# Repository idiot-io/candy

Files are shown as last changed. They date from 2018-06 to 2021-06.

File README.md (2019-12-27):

more at [idiot.io](idiot.io)

# candy
Electrodible lolliPCBpops

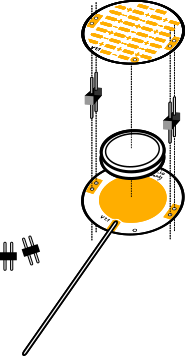
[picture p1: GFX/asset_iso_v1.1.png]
iso look
 

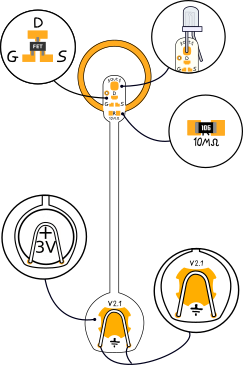
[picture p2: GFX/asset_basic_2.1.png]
basic look
 

34c3 [video](https://www.youtube.com/watch?v=yhNaNCrcmBk) cooking show and talk  

## tools
using [inkscape](https://inkscape.org) with [svg2shenzen](https://github.com/badgeek/svg2shenzhen) extension - a wrapper/fork to [Kicad's](https://kicad.github.io) own bitmap2component plugin.  
basicly - design a board in SVG vector format and export it as gerber files, ready for fabrication.  

included in the repo is a script to automate the gerber file generation.  
so after you run `extensins>svg2shenzhen>export`  
run  
```python2 ../kicad_gerber_gen.py IRiotCandy-svg2shnzn.kicad_pcb```

[gerbv](http://gerbv.geda-project.org) was then used to preview the gerber output and move the silkscreen to its right position. if you have it in your path, the previous python script should auto open the generate dgerber files fo you.

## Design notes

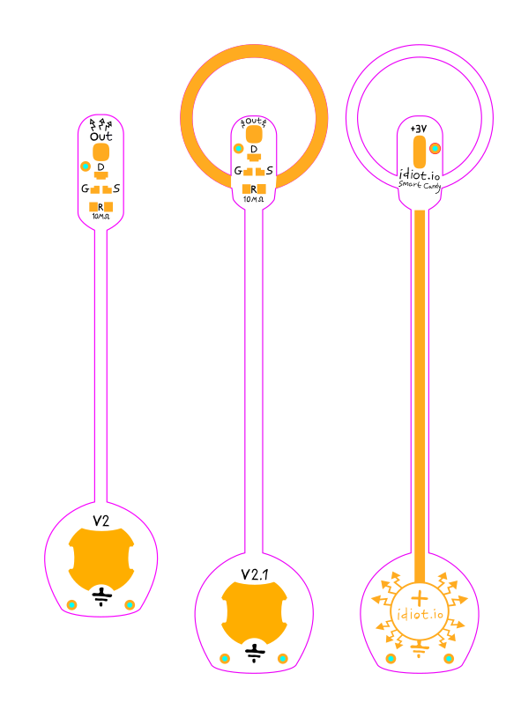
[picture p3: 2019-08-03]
hardware/BasicCandyV2.1.png

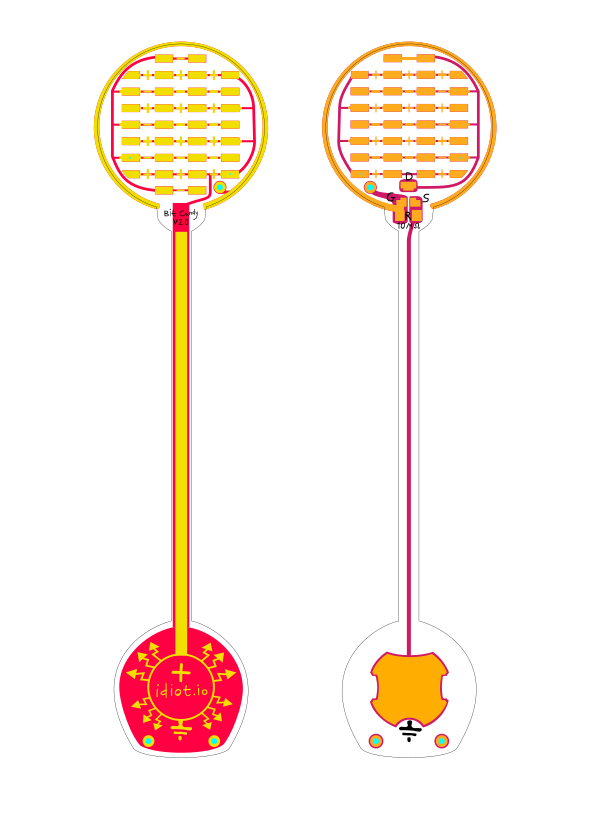
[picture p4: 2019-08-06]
hardware/BitCandyV2.0.png

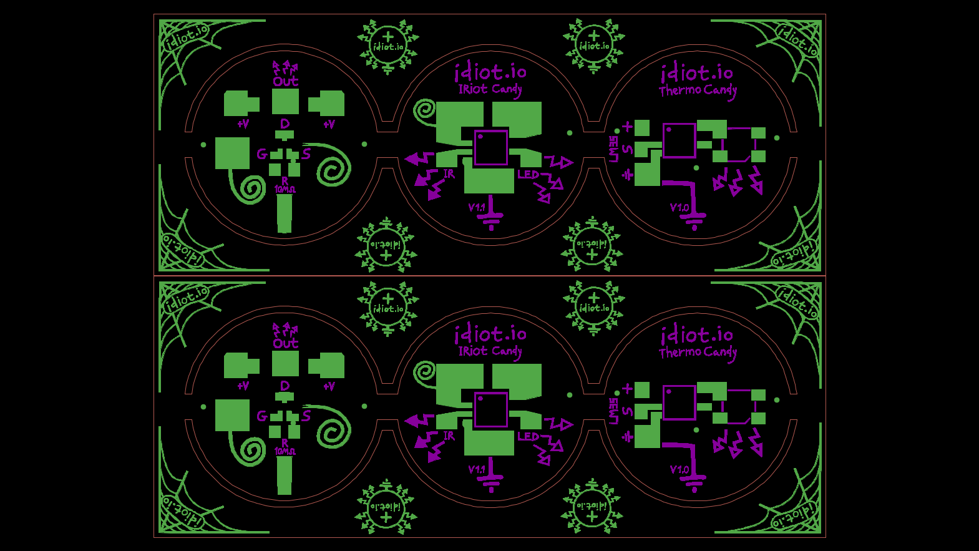
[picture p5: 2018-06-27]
hardware/releases/gerber-panelInkscape-double.png

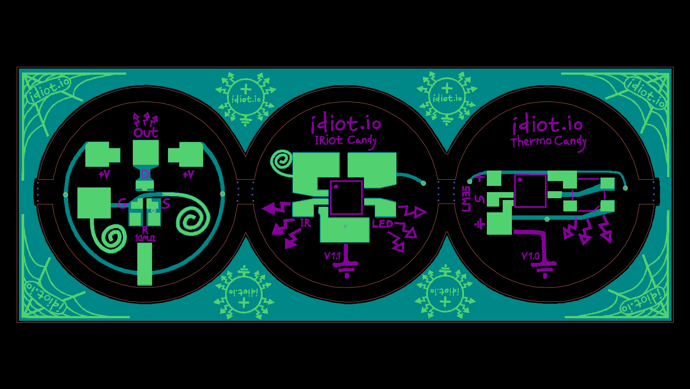
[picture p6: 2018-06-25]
hardware/releases/gerber-panelInkscape.png

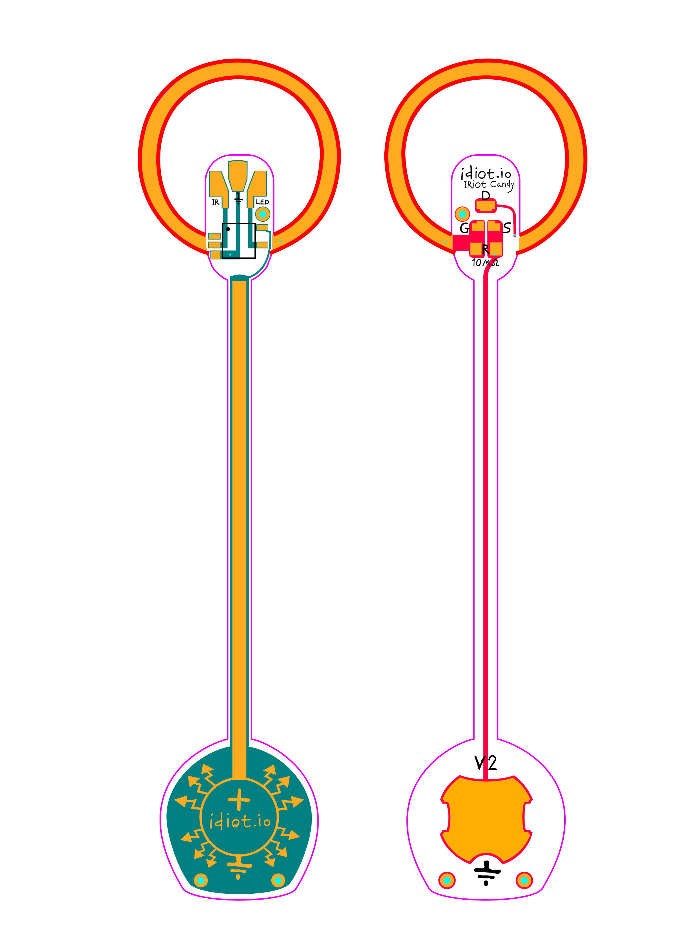
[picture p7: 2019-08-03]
hardware/IRiotCandyV2.0.png

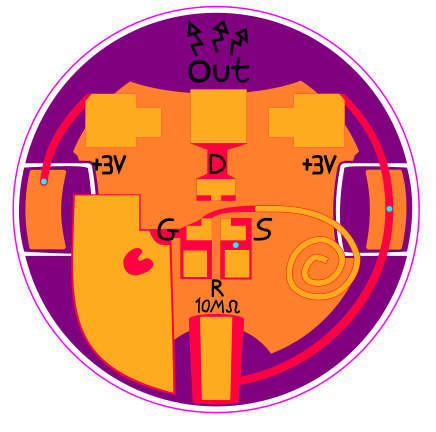
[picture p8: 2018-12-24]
hardware/releases/basicCandy-single-24122018.png

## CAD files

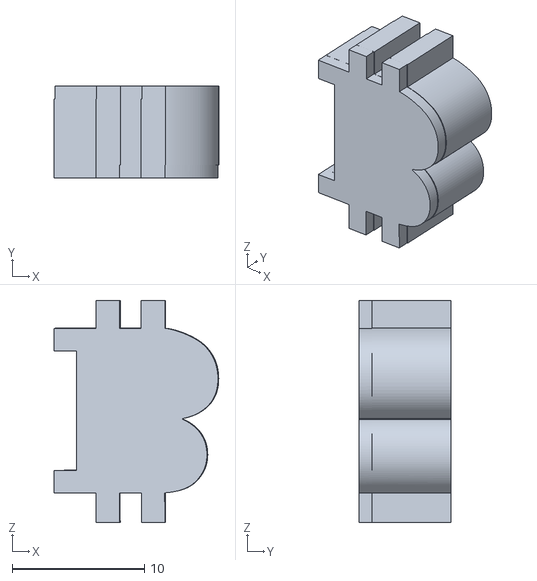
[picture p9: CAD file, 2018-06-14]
GFX/stl-models/candycoin.stl
12.5 x 7.00 x 16.8

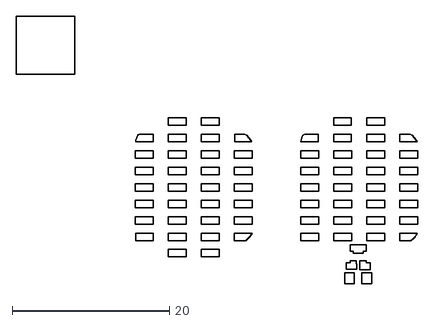
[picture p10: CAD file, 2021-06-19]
hardware/BitCandyStencil/BitCandyStencil.dxf
51.1 x 34.1

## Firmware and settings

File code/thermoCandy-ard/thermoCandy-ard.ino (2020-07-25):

/*
  ThermoCandy
   for kids only

   words http://idiot.io
   code https://github.com/shenkarSElab/IRiot/thermoCandy

   pin out attiny85
   NC      -1+----+8- VCC
   NC      -2|*   |7- NC
   Thermo  -3|    |6- Pixel
   GND     -4+----+5- Serial (debug)
   http://drazzy.com/e/img/PinoutT85a.jpg
*/

///////////////////////////////////////////////
///https://forum.arduino.cc/index.php?topic=112013.msg841582#msg841582
#include "SendOnlySoftwareSerial.h"
SendOnlySoftwareSerial mySerial (0);  // Tx pin , PB0, pin5

////////////////////////////////////////////////
//https://github.com/adafruit/Adafruit_NeoPixel
#include <Adafruit_NeoPixel.h>
#ifdef __AVR__
#include <avr/power.h>
#endif
#define pixelPin 1 //PB1, pin6
Adafruit_NeoPixel pixels = Adafruit_NeoPixel(1, pixelPin, NEO_GRB + NEO_KHZ800);

///////////////////////////////
// https://github.com/MajenkoLibraries/Average
#include "Average.h"
Average<float> ave(30);
int sensorPin = A2; //pin 3


//pixels
byte red, green, blue;

//#define range 0 //RAINBOWS
#define range 1 //test heat
//#define range 2   //fancy

int ledState, getout, blinkRate;
unsigned long prevMillis1, prevMillis2  = 0;

void setup() {
  mySerial.begin(9600);

  pixels.begin();
}

void loop() {
  unsigned long currentMillis = millis();

  int analogValue = analogRead(sensorPin);
  long temperature = (readVcc() / 1000.0) * analogValue * 100.0 / 1024;

  ave.push(temperature);
  float average = ave.mean();


  switch (range) {
    case 0:
      //rainbows pixel test
      for (int i = 0; i < 255; i++) {
        green = i;
        red = i - 255;
        blue = 0;
      }
      break;
    case 1:
      getout = 0;
      if (average > 20  && average < 35) {
        red = 0;
        green = 255;
        blue = 0;
      } else if (average >= 36.5 && average < 120) {
        red = 200;
        green = 0;
        blue = 0;
      } else if (average >= 120) {

        getout = 1;

        blinkRate = map( constrain(average, 146, 120) , 146, 120, 500, 50);
        red = ledState * 255;
        green = 0;
        blue = 0;
      }


      break;
    case 2:
      //fancy
      byte red, green, blue;
      if (average > 20  && average < 35) {
        green = mapfloat(average, 20, 37, 0, 255);
        blue = 255 - red;
        red = 0;
      } else if (average >= 35  && average < 36.5) {
        red = mapfloat(average, 24, 37, 0, 255);
        green = 255 - red;
        blue = 0;
      } else if (average >= 36.5 && average < 100) {
        red = mapfloat(average, 36.5, 37, 0, 255);
        green = 0;
        blue = 0;
      } else if (average >= 100) {
        red = ledState;
        green = 0;
        blue = 0;
      }

      break;
  }


  pixels.setPixelColor(0, pixels.Color(red, green, blue));
  pixels.show();

  if (currentMillis - prevMillis1 >= 50) {

    // And show some interesting results.
    mySerial.print(average);
    mySerial.print(" ");
    mySerial.print(temperature);

    mySerial.print(" ");
    mySerial.print(blinkRate);
    mySerial.print(" ");
    mySerial.print(ledState);

    /*
        mySerial.print(" ");
        mySerial.print(red);
        mySerial.print(" ");
        mySerial.print(green);
        mySerial.print(" ");
        mySerial.print(blue);
    */
    mySerial.println();
  }

  //700=interval
  if (currentMillis - prevMillis2 >= blinkRate) {
    prevMillis2 = currentMillis;
    if (ledState) {
      ledState = false;
    } else {
      ledState = true;
    }
  }


}
// This code snippet is made by Tinkerit. Open Source license. Slightly modified by DavidJWatts
long readVcc() {
  // Read 1.1V reference against AVcc
  long result;
  // set the reference to Vcc and the measurement to the internal 1.1V reference
  ADMUX = _BV(MUX3) | _BV(MUX2);

  delay(2); // Wait for Vref to settle
  ADCSRA |= _BV(ADSC); // Convert
  while (bit_is_set(ADCSRA, ADSC));
  result = ADCL;
  result |= ADCH << 8;
  result = 1126400L / result; // Back-calculate AVcc in mV
  return result;
}

float mapfloat(long x, long in_min, long in_max, long out_min, long out_max)
{
  return (float)(x - in_min) * (out_max - out_min) / (float)(in_max - in_min) + out_min;
}

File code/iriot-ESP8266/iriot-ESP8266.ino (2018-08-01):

/*
    test on your server with
    $ mosquitto_sub -h 127.0.0.1 -i testSub -t outLicks
  =ESP8266 board=
  //  to install ESP8266 in arduino IDE
  https://github.com/esp8266/Arduino#installing-with-boards-manager

  =libraries to install=
    adafruit gfx library
    adafruit SSD1306
    IRremoteWSP8266
    PubSubClient
    WifiManager

  =nodeMCU pinout =
    ==IR CHQ1838==
    // package facing you
    // from left to right
    D5/14
    GND
    3V3

    ==OLED SD1306==
    GND
    3V3
    D1/SCL
    D2/SDA
*/

/////////////////////////////////////////////////////////////////////////////
//wifi manager     https://github.com/tzapu/WiFiManager
#include <ESP8266WiFi.h>          //https://github.com/esp8266/Arduino
#include <DNSServer.h>
#include <ESP8266WebServer.h>
#include <WiFiManager.h>

/////////////////////////////////////////////////////////////////////////////
//irRemote code https://github.com/markszabo/IRremoteESP8266/wiki#ir-receiving
#include <IRremoteESP8266.h>
#include <IRrecv.h>
#include <IRutils.h>
uint16_t RECV_PIN = 14; // An IR detector/demodulator is connected to GPIO pin 14(D5 on a NodeMCU).
IRrecv irrecv(RECV_PIN);
decode_results results;

/////////////////////////////////////////////////////////////////////////////
//mqtt broker https://github.com/knolleary/pubsubclient - http://pubsubclient.knolleary.net/
#include <PubSubClient.h>
WiFiClient espClient;
PubSubClient client(espClient);
const char* mqtt_server = "idiot.io";

/////////////////////////////////////////////////
//// OLED aliexpress ssd1306
// see setup https://www.youtube.com/watch?v=RpK7-Ljnpho
#include <Adafruit_GFX.h>
#include <Adafruit_SSD1306.h>
#define SSD1306_LCDHEIGHT 64
#define OLED_RESET LED_BUILTIN
Adafruit_SSD1306 display(OLED_RESET);

#include "imageidiot.h"


///////////////////////////////////////////////
// pysicals
#define ledStatus 2
int linecount = 0;

void setup() {
  Serial.begin(115200);
  Serial.println("starting..");

  //OLED
  display.begin(SSD1306_SWITCHCAPVCC, 0x3C);
  display.clearDisplay();
  display.setCursor(0, 0);
  display.drawBitmap(0, 0, idiotio_Logo_bits, idiotio_Logo_width, idiotio_Logo_height, 1);
  display.display();

  display.setTextSize(1);
  display.setTextColor(WHITE, BLACK);
  display.setCursor(0, 0);

  //wifi manger
  WiFiManager wifiManager;
  wifiManager.autoConnect("AutoConnectAP");
  Serial.println("connected...");

  //IRrecv
  irrecv.enableIRIn();  // Start the receiver

  //MQTT
  client.setServer(mqtt_server, 1883);
  client.setCallback(callback);

  pinMode(ledStatus, OUTPUT);
  digitalWrite(ledStatus, LOW);

  delay(1500);

  display.fillRect(4, 35, 108, 29, BLACK);
  display.setCursor(4, 35);
  display.print(WiFi.localIP().toString());
  display.display();


}

void loop() {


  //mqtt loop
  if (!client.connected()) {
    reconnect();
  }
  client.loop();

  //ir recv callback
  if (irrecv.decode(&results)) {
    digitalWrite(ledStatus, HIGH);

    //mqtt
    String txt = uint64ToString(results.value, 16);
    char charBuf[50];
    txt.toCharArray(charBuf, 16);

    client.publish("outLicks", charBuf );

    Serial.print("sending: ");
    Serial.println(charBuf);

    //IR sig
    //limited to 2 row, then need to jump up 8*2 on y
    display.setCursor(4, 43 + ((linecount % 2) * 8));
    display.print("sending: ");  display.print(charBuf);
    display.display();
    linecount++;

    delay(100);

    irrecv.resume();  // Receive the next value

    digitalWrite(ledStatus, LOW);
    /*
      ++value;
      snprintf (msg, 128, "licked %lld @ %ld", results.value, millis() );

      Serial.print("Publish message: ");
      Serial.println(msg);
      client.publish("outLicks", msg);

      // print() & println() can't handle printing long longs. (uint64_t)
      serialPrintUint64(results.value, HEX);
      Serial.println("");
    */
  }
}

//MQTT functions
void callback(char* topic, byte* payload, unsigned int length) {
  Serial.print("Message arrived [");
  Serial.print(topic);
  Serial.print("] ");
  for (int i = 0; i < length; i++) {
    Serial.print((char)payload[i]);
  }
  Serial.println();
}
void reconnect() {
  // Loop until we're reconnected
  while (!client.connected()) {
    Serial.print("Attempting MQTT connection...");
    // Attempt to connect
    if (client.connect("arduinoClient")) {
      Serial.println("connected");
      // Once connected, publish an announcement...
      client.publish("outTopic", "hello world");
      // ... and resubscribe
      client.subscribe("inTopic");
    } else {
      Serial.print("failed, rc=");
      Serial.print(client.state());
      Serial.println(" try again in 5 seconds");
      // Wait 5 seconds before retrying
      delay(5000);
    }
  }
}

void testdrawchar(void) {
  display.setTextSize(1);
  display.setTextColor(WHITE);
  display.setCursor(0, 0);

  for (uint8_t i = 0; i < 168; i++) {
    if (i == '\n') continue;
    display.write(i);
    if ((i > 0) && (i % 21 == 0))
      display.println();
  }
  display.display();
  delay(1);
}

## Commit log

2018-03-08 has candy, too big pads
    [candy.brd, candy.sch]
2018-03-09 with ugly polygons on layout
    [candy.brd, candy.sch]
2018-03-12 fixed schema and added 2n222
    [candy.brd, candy.sch]
2018-03-12 board ready for silk
    [BasicCandySilk_plain2.dxf, candy.brd, candy.sch]
2018-03-12 removed frame
    [candy.sch]
2018-03-12 stright gerber
    [copper_bottom.gbr, copper_top.gbr, drills.xln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]
2018-03-13 shifted a bit
    [BasicCandySilk_plain2.dxf, candy.brd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]
2018-05-16 no pours, smd and npn
    [candy.brd]
2018-05-17 stick on front
    [candy.brd, candy.sch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]
2018-05-17 gerber with svg2shanzen
    [candyShnzhensvg-B.SilkS.gbr, candyShnzhensvg-F.SilkS.gbr, copper_bottom.GBL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]
2018-05-17 gerber ready
    [candy.brd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]
2018-06-02 added Mosfet connections
2018-06-10 minor changs to iRiot board
2018-06-14 merged all files from IRiot repo
    [candycoin.stl]
2018-06-19 drills needs to be merged
2018-06-19 first gerber, need to remove copper aroudn drills
2018-06-21 moved files
    [panel-inkscape-candy-double.kicad_pcb, panel-inkscape-candy.kicad_pcb]
2018-06-22 panel 3mm border
2018-06-22 3mm border gerbers
2018-06-23 added IR&LED silk on IRiot
2018-06-23 added new GND GFX
    DONE!!!
2018-06-23 new panel
    [panel-inkscape-candy.kicad_pcb]
2018-06-26 upped the drill size to 0.4mm
2018-06-26 sent to fab
    [panel-inkscape-candy.kicad_pcb]
2018-06-27 thinner outlines, more back ground space
    [panel-inkscape-candy.kicad_pcb]
2018-07-05 restructure dirs
    [panel-inkscape-candy.kicad_pcb]
2018-07-10 added v1.2+
    all numbers are in seperate layer and
    also fixed logo silkscreen on both sides
2018-07-23 kicad idiot.io parts
2018-07-23 remove kicad lib to its own repo https://github.com/idiot-io/idiot-io-assets
2018-08-01 flip led pin in iriot code, no random nec ir, svg bottom panel
    [iriot-ESP8266.ino, iriot-ard.ino]
2018-12-23 v1.3
    fixed +3v and v1.3
2019-02-03 mask and drills dist
2019-02-03 kicad export
    [BitCandyV1.0.kicad_pcb]
2019-02-04 GND bridge at wrong layer fixfixfix
2019-02-04 enlargeGpad+hole fixx
2019-02-05 moved up gnd>D trace
2019-02-06 bitCandy , plotted
    [BitCandyV1.0.kicad_pcb]
2019-02-21 broke apart evil group in drill layer
2019-03-04 added sleep and lickometer circuit code
2019-03-06 IRriot gerber
2019-04-22 fix for groups in drill
    [BitCandyV1.0.kicad_pcb]
2019-05-01 added a win bacth script to the export to plot stage
2023-07-23 kicad 6 and py 3
